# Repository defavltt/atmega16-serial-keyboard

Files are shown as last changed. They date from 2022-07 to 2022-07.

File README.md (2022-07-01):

# ATmega16 serial keyboard

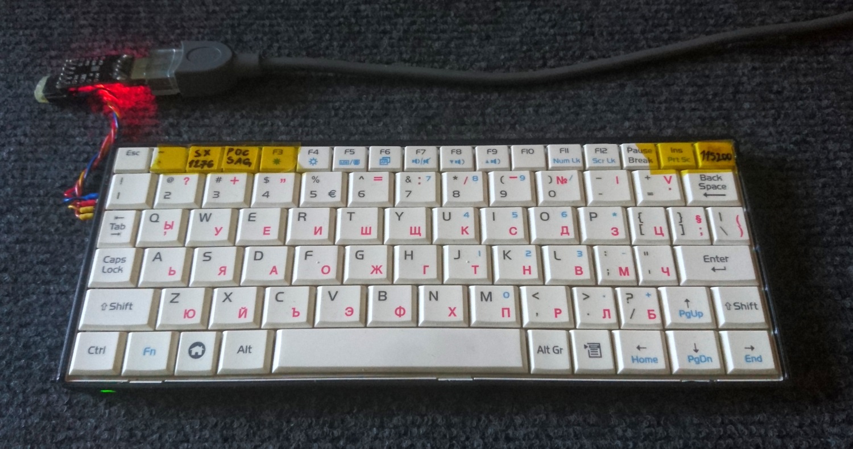
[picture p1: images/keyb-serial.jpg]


## Features

 - Key macros can be added in code
 
 - Caps toggle with LED indication
 
 - Select 115200 serial baud rate at power up (9600 default)
 
 - Send values outside ASCII range with non letter keys
 
 - Works with laptop mini keyboards 26-pin (28-pin with 2 being a short)

## Operation

When powering up, while the LED is lit, you can choose either: 9600 baud by not pressing DEL or 115200 by pressing DEL. After that you can choose a macro key mapping preset with F1 - F12. Finally when the LED is off you can start typing.

Toggling caps lock is done by a single press on the caps key. Shift key inverts it. When caps is on, the numbers change into symbols too.

_When designing an application at the other end of the serial cable, you may consider to take advantage of the non letter keys that send values (>200), as interface navigation. For example: ESC to exit out of options, HOME to exit out to start screen, ENTER to send a message or save an option, arrow keys for navigating through options and F1 - F12 for predefined functions._

# Hardware

Can be made with ATmega16/164/32/324/644/1284/8535 (44pin TQFP packege).

For 115200 serial baud rate a 16Mhz or a different suitable crystal is required, even though it's not included in the board design.
Board is designed for single side etching and some wire jumpers, vias are only for ground connection to the bottom layer. Feel free to improve it.

There are pads left on the PCB for ISP programming.

File for a 3D printed case is included. This case only suits keyboards with frame size - 211mm x 80mm.

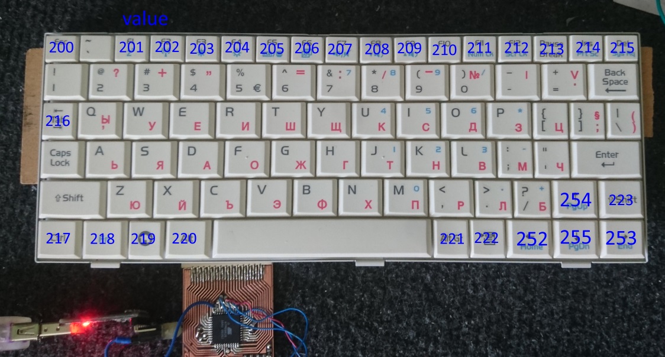
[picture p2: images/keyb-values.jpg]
  
_values that can be sent from the corresponding keys_

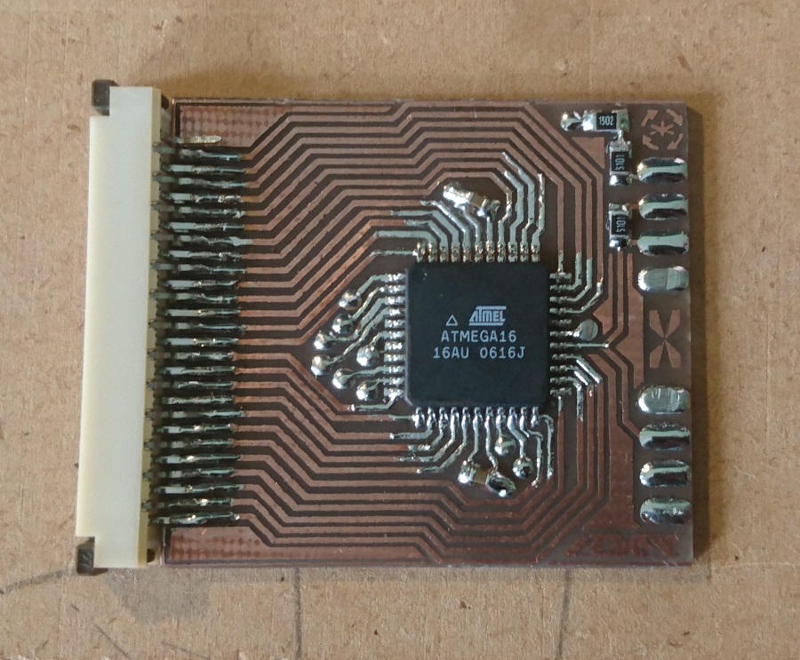
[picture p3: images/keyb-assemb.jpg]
  
_assembled board only with components, no jumper wires or crystal_

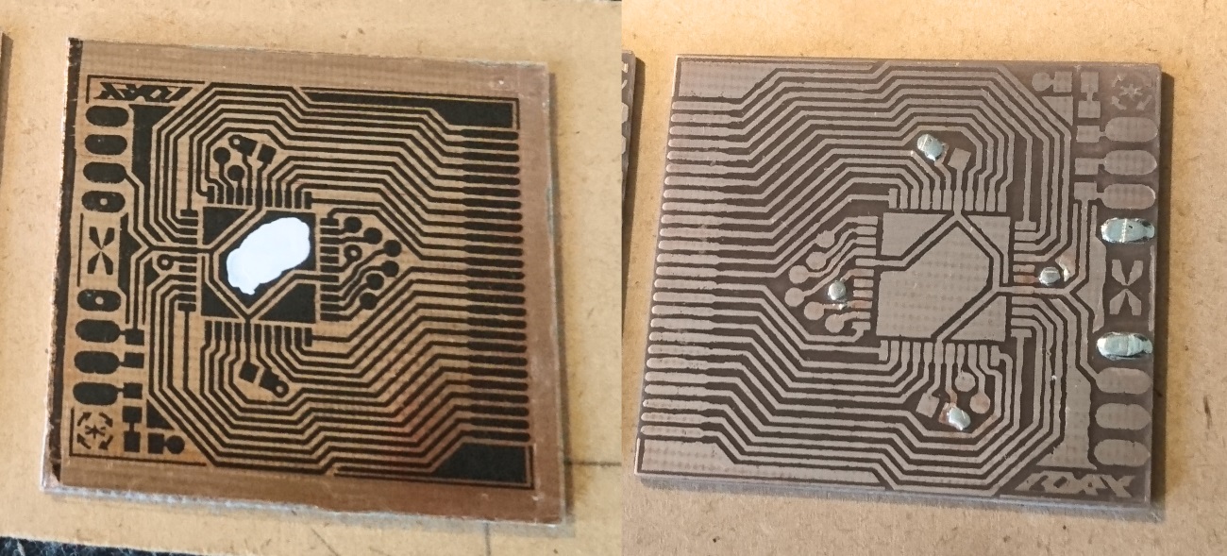
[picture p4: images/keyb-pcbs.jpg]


_< toner layer to protect copper from etchant | etched pcb >_

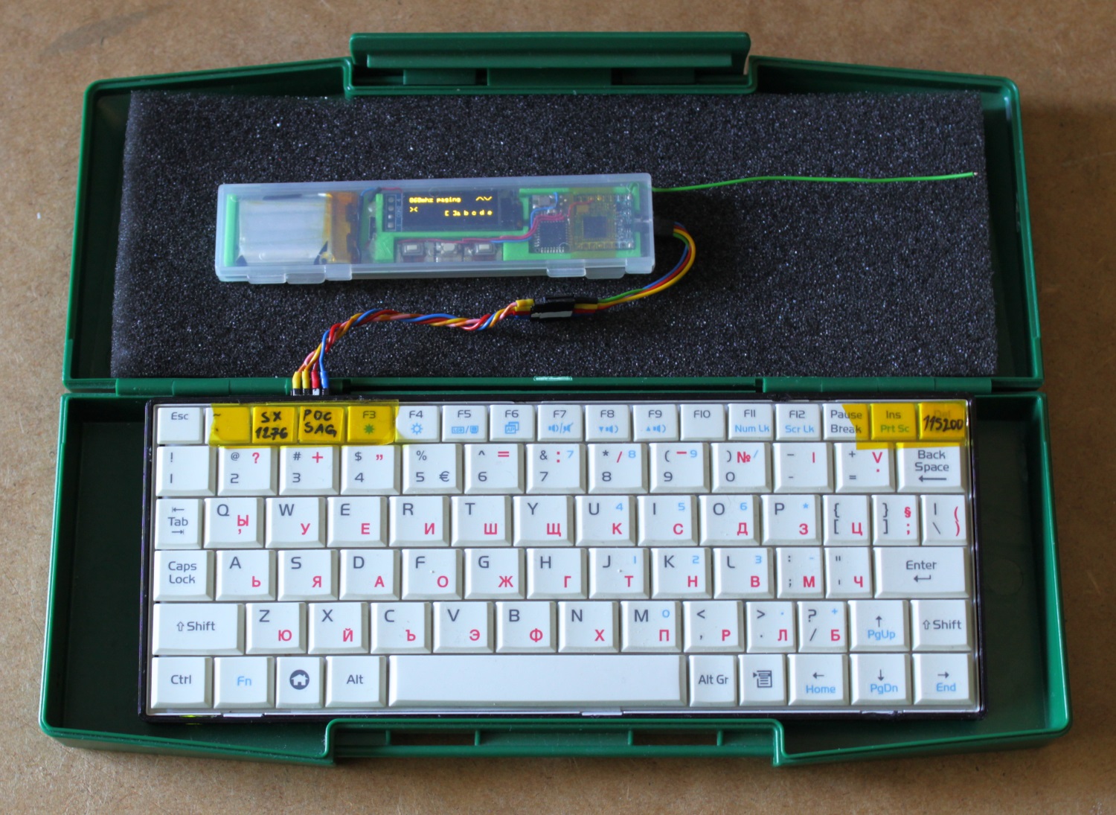
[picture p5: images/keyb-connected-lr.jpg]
  
_serial keyboard connected to a RFM95 LoRa communicator_

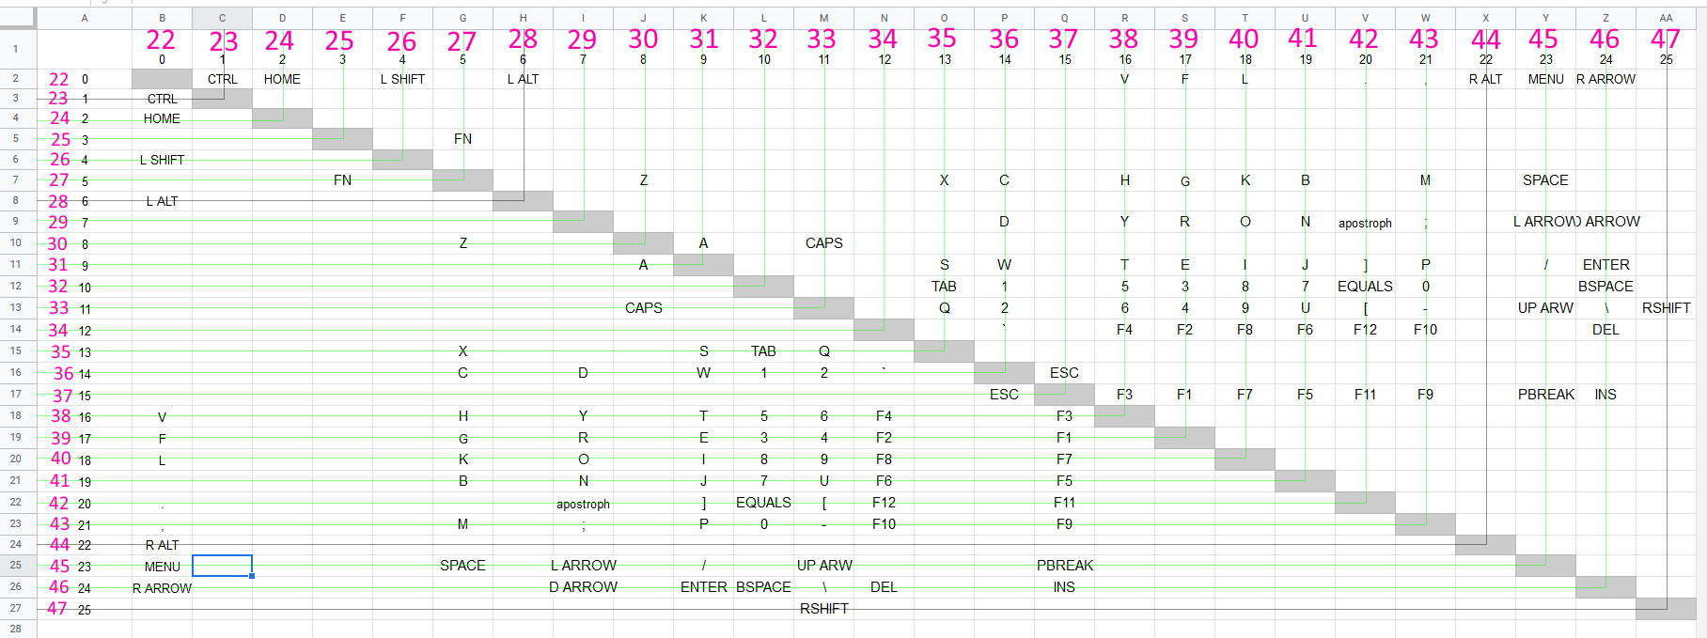
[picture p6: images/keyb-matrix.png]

_keyboard ribbon cable pin multiplexing mapping_

# Programming

 - Download and install [MightyCore](https://github.com/MCUdude/MightyCore)
 
 - Open code in IDE of choice
 
 - Configure board settings
 
   - Select your MCU and crystal frequency
   
   - Leave the rest of the board settings by default
   
   - If want, you can enable bootloader and leave out a reset pin on the serial connector for future configuring of the key macros.
   
 - Flash via ISP programmer and it's done.

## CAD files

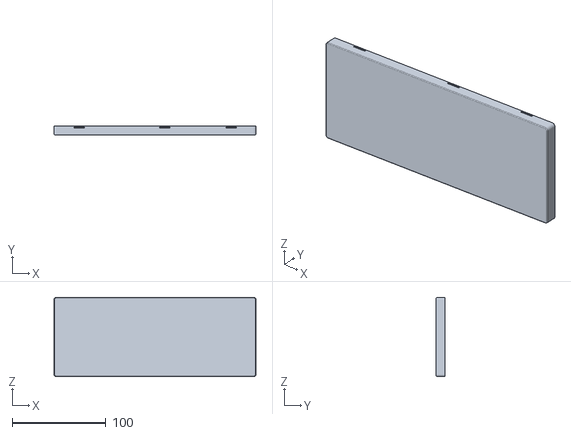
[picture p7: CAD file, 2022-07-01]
hardware/case/laptop keyboard case.stl
215.5 x 9.50 x 84.5

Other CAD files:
hardware/case/laptop keyboard case.f3d

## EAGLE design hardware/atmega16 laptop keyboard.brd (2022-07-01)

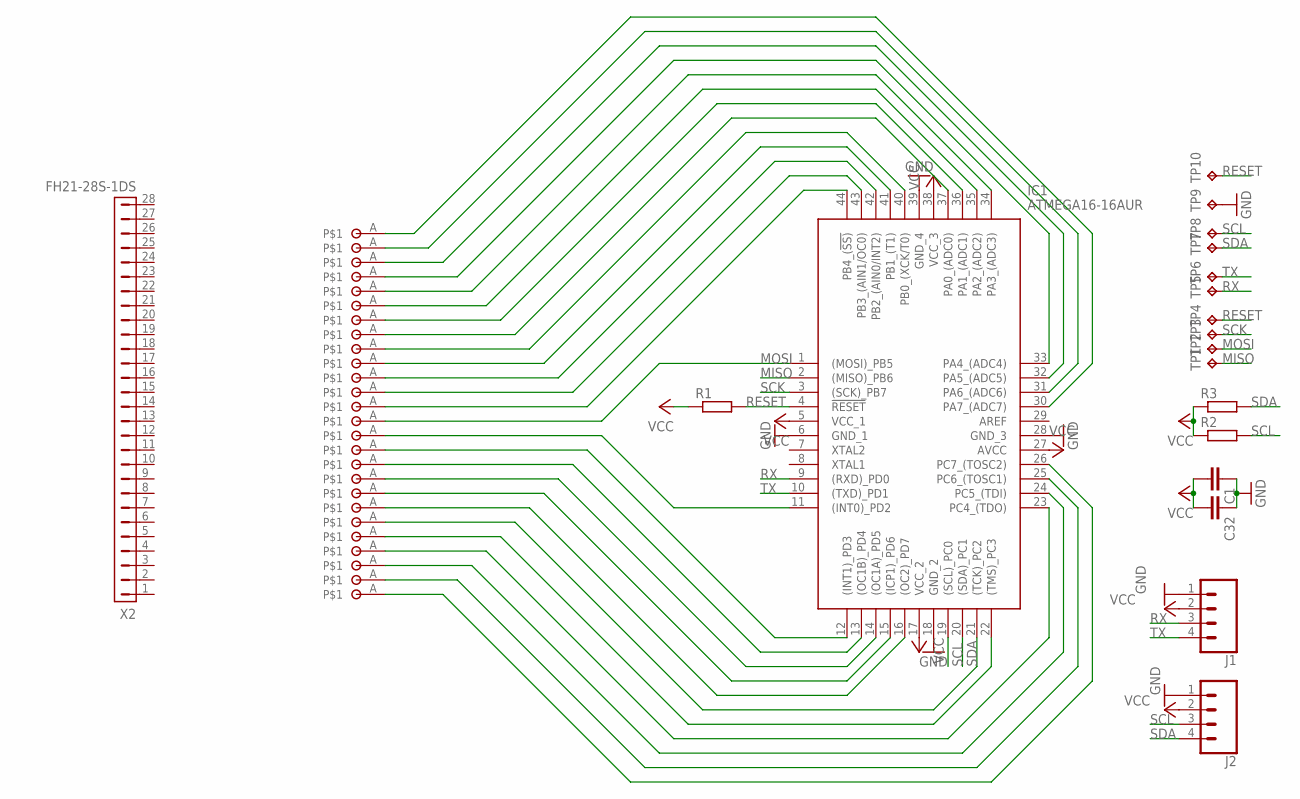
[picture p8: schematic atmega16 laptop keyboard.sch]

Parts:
C1, C32: C-EUC0805; C0805
IC1: ATMEGA16-16AUR; QFP80P1200X1200X120-44N
J1, J2: CONN_04LONGPADS; 1X04_LONGPADS
R1, R2, R3: R-EU_M0805; M0805
TP1, TP2, TP3, TP4, TP5, TP6, TP7, TP8, TP9, TP10: TPTP15R; TP15R
U$1, U$2, U$3, U$4, U$5, U$6, U$7, U$8, U$9, U$10, U$11, U$12, U$13, U$14, U$15, U$16, U$17, U$18, U$19, U$20, U$21, U$22, U$23, U$24, U$25, U$26: PAD1
X2: FH21-28S-1DS

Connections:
GND: C1.1, C32.1, IC1.6 (GND_1), IC1.18 (GND_2), IC1.28 (GND_3), IC1.39 (GND_4), J1.1, J2.1, TP9.TP
MISO: IC1.2 ((MISO)_PB6), TP1.TP
MOSI: IC1.1 ((MOSI)_PB5), TP2.TP, U$14.A
unnamed: IC1.11 ((INT0)_PD2), U$15.A
unnamed: IC1.12 ((INT1)_PD3), U$16.A
unnamed: IC1.13 ((OC1B)_PD4), U$17.A
unnamed: IC1.14 ((OC1A)_PD5), U$18.A
unnamed: IC1.15 ((ICP1)_PD6), U$19.A
unnamed: IC1.16 ((OC2)_PD7), U$20.A
unnamed: IC1.21 ((TCK)_PC2), U$21.A
unnamed: IC1.22 ((TMS)_PC3), U$22.A
unnamed: IC1.23 (PC4_(TDO)), U$23.A
unnamed: IC1.24 (PC5_(TDI)), U$24.A
unnamed: IC1.25 (PC6_(TOSC1)), U$25.A
unnamed: IC1.26 (PC7_(TOSC2)), U$26.A
unnamed: IC1.44 (PB4_(!SS)), U$13.A
unnamed: IC1.43 (PB3_(AIN1/OC0)), U$12.A
unnamed: IC1.42 (PB2_(AIN0/INT2)), U$11.A
unnamed: IC1.41 (PB1_(T1)), U$10.A
unnamed: IC1.40 (PB0_(XCK/T0)), U$9.A
unnamed: IC1.37 (PA0_(ADC0)), U$8.A
unnamed: IC1.36 (PA1_(ADC1)), U$7.A
unnamed: IC1.35 (PA2_(ADC2)), U$6.A
unnamed: IC1.34 (PA3_(ADC3)), U$5.A
unnamed: IC1.33 (PA4_(ADC4)), U$4.A
unnamed: IC1.32 (PA5_(ADC5)), U$3.A
unnamed: IC1.31 (PA6_(ADC6)), U$2.A
unnamed: IC1.30 (PA7_(ADC7)), U$1.A
RESET: IC1.4 (!RESET), R1.2, TP4.TP, TP10.TP
RX: IC1.9 ((RXD)_PD0), J1.3, TP5.TP
SCK: IC1.3 ((SCK)_PB7), TP3.TP
SCL: IC1.19 ((SCL)_PC0), J2.3, R2.2, TP8.TP
SDA: IC1.20 ((SDA)_PC1), J2.4, R3.2, TP7.TP
TX: IC1.10 ((TXD)_PD1), J1.4, TP6.TP
VCC: C1.2, C32.2, IC1.5 (VCC_1), IC1.17 (VCC_2), IC1.27 (AVCC), IC1.38 (VCC_3), J1.2, J2.2, R1.1, R2.1, R3.1

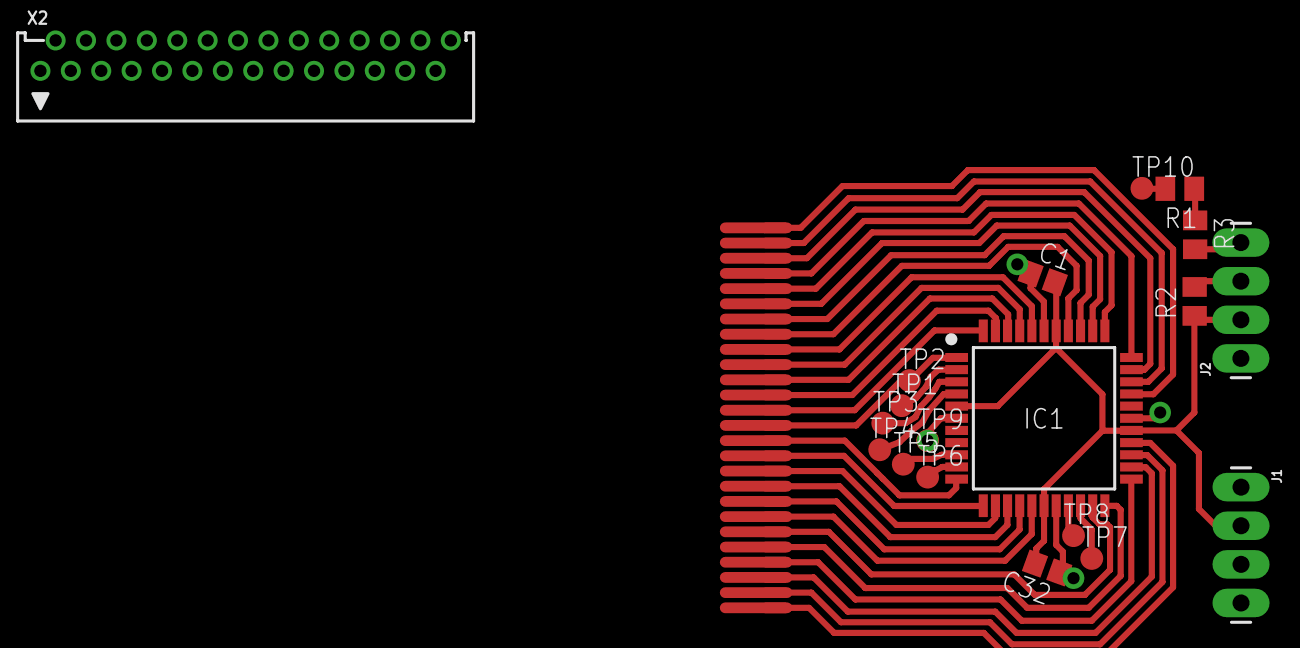
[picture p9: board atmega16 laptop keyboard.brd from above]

Board: 2 copper layers, 45 parts (0 on the bottom side), 35 nets.

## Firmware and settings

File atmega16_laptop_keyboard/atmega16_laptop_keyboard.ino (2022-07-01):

#define DR(port, pin) !((port >> pin) & B00000001) //fast pin reading

#define p22(state) if(DR(PINC, 6) == HIGH && DR(PINC, 6) != state) { statebuffer = 1; } else { statebuffer = 0; }  state = DR(PINC, 6);
#define p23(state) if(DR(PINC, 7) == HIGH && DR(PINC, 7) != state) { statebuffer = 1; } else { statebuffer = 0; }  state = DR(PINC, 7);
#define p24(state) if(DR(PINC, 4) == HIGH && DR(PINC, 4) != state) { statebuffer = 1; } else { statebuffer = 0; }  state = DR(PINC, 4);
#define p25(state) if(DR(PINC, 5) == HIGH && DR(PINC, 5) != state) { statebuffer = 1; } else { statebuffer = 0; }  state = DR(PINC, 5);
#define p26(state) if(DR(PINC, 2) == HIGH && DR(PINC, 2) != state) { statebuffer = 1; } else { statebuffer = 0; }  state = DR(PINC, 2);
#define p27(state) if(DR(PINC, 3) == HIGH && DR(PINC, 3) != state) { statebuffer = 1; } else { statebuffer = 0; }  state = DR(PINC, 3);
#define p28(state) if(DR(PIND, 6) == HIGH && DR(PIND, 6) != state) { statebuffer = 1; } else { statebuffer = 0; }  state = DR(PIND, 6);
#define p29(state) if(DR(PIND, 7) == HIGH && DR(PIND, 7) != state) { statebuffer = 1; } else { statebuffer = 0; }  state = DR(PIND, 7);
#define p30(state) if(DR(PIND, 4) == HIGH && DR(PIND, 4) != state) { statebuffer = 1; } else { statebuffer = 0; }  state = DR(PIND, 4);
#define p31(state) if(DR(PIND, 5) == HIGH && DR(PIND, 5) != state) { statebuffer = 1; } else { statebuffer = 0; }  state = DR(PIND, 5);
#define p32(state) if(DR(PIND, 2) == HIGH && DR(PIND, 2) != state) { statebuffer = 1; } else { statebuffer = 0; }  state = DR(PIND, 2);
#define p33(state) if(DR(PIND, 3) == HIGH && DR(PIND, 3) != state) { statebuffer = 1; } else { statebuffer = 0; }  state = DR(PIND, 3);
#define p34(state) if(DR(PINB, 4) == HIGH && DR(PINB, 4) != state) { statebuffer = 1; } else { statebuffer = 0; }  state = DR(PINB, 4);
#define p35(state) if(DR(PINB, 5) == HIGH && DR(PINB, 5) != state) { statebuffer = 1; } else { statebuffer = 0; }  state = DR(PINB, 5);
#define p36(state) if(DR(PINB, 2) == HIGH && DR(PINB, 2) != state) { statebuffer = 1; } else { statebuffer = 0; }  state = DR(PINB, 2);
#define p37(state) if(DR(PINB, 3) == HIGH && DR(PINB, 3) != state) { statebuffer = 1; } else { statebuffer = 0; }  state = DR(PINB, 3);
#define p38(state) if(DR(PINB, 0) == HIGH && DR(PINB, 0) != state) { statebuffer = 1; } else { statebuffer = 0; }  state = DR(PINB, 0);
#define p39(state) if(DR(PINB, 1) == HIGH && DR(PINB, 1) != state) { statebuffer = 1; } else { statebuffer = 0; }  state = DR(PINB, 1);
#define p40(state) if(DR(PINA, 1) == HIGH && DR(PINA, 1) != state) { statebuffer = 1; } else { statebuffer = 0; }  state = DR(PINA, 1);
#define p41(state) if(DR(PINA, 0) == HIGH && DR(PINA, 0) != state) { statebuffer = 1; } else { statebuffer = 0; }  state = DR(PINA, 0);
#define p42(state) if(DR(PINA, 3) == HIGH && DR(PINA, 3) != state) { statebuffer = 1; } else { statebuffer = 0; }  state = DR(PINA, 3);
#define p43(state) if(DR(PINA, 2) == HIGH && DR(PINA, 2) != state) { statebuffer = 1; } else { statebuffer = 0; }  state = DR(PINA, 2);
#define p44(state) if(DR(PINA, 5) == HIGH && DR(PINA, 5) != state) { statebuffer = 1; } else { statebuffer = 0; }  state = DR(PINA, 5);
#define p45(state) if(DR(PINA, 4) == HIGH && DR(PINA, 4) != state) { statebuffer = 1; } else { statebuffer = 0; }  state = DR(PINA, 4);
#define p46(state) if(DR(PINA, 7) == HIGH && DR(PINA, 7) != state) { statebuffer = 1; } else { statebuffer = 0; }  state = DR(PINA, 7);
#define p47(state) if(DR(PINA, 6) == HIGH && DR(PINA, 6) != state) { statebuffer = 1; } else { statebuffer = 0; }  state = DR(PINA, 6);

bool statebuffer;

bool keystate[81];

bool shiftkey;
bool capskey;

/*key macro presets*/
byte mode = 0; //0 - default map, 1 - sx1276 config, 2 - pocsag config

void setup() {
  Serial.begin(9600);
  pinMode(PIN_PC0, OUTPUT); //caps led
  
  while(true) {
    pulluppins();
    pinMode(PIN_PB4, OUTPUT);
    digitalWrite(PIN_PB4, LOW);
    p38(keystate[64]) if(statebuffer) { //38
      mode = 4; //F4
    }
    p39(keystate[65]) if(statebuffer) { //39
      mode = 2; //F2
    }
    p40(keystate[66]) if(statebuffer) { //40
      mode = 8; //F8
    }
    p41(keystate[67]) if(statebuffer) { //41
      mode = 6; //F6
    }
    p42(keystate[68]) if(statebuffer) { //42
      mode = 12; //F12
    }
    p43(keystate[69]) if(statebuffer) { //43
      mode = 10; //F10
    }
    p46(keystate[70]) if(statebuffer) { //46
      Serial.begin(115200); //DEL
    }
  
    pulluppins();
    pinMode(PIN_PB3, OUTPUT);
    digitalWrite(PIN_PB3, LOW);
    p38(keystate[72]) if(statebuffer) { //38
      mode = 3; //F3
    }
    p39(keystate[73]) if(statebuffer) { //39
      mode = 1; //F1
    }
    p40(keystate[74]) if(statebuffer) { //40
      mode = 7; //F7
    }
    p41(keystate[75]) if(statebuffer) { //41
      mode = 5; //F5
    }
    p42(keystate[76]) if(statebuffer) { //42
      mode = 11; //F11
    }
    p43(keystate[77]) if(statebuffer) { //43
      mode = 9; //F9
    }
    
    shiftkey = 1; //turn on led by enabling shift
    if(millis() > 3000) {
      return;
    }
  }
  shiftkey = 0; //turn off led by letting shift off


  
}

void loop() {
  scankeyboard();

}

void scankeyboard() {
  column0();
  column3();
  column5();
  column7();
  column8();
  column9();
  column10();
  column11();
  column12();
  column14();
  column15();
  
//  digitalWrite(PIN_PC0, shiftkey); //caps led
}

void pulluppins() {
  DDRC = 0b00000001; //make input
  if(shiftkey) {
    PORTC = 0b11111101; //1-6 //pull up
  } else {
    PORTC = 0b11111100; //1-6 //pull up
  }
  DDRD = 0b00000000;
  PORTD = 0b11111100; //7-12
  DDRB = 0b00000000;
  PORTB = 0b00111111; //13-18
  DDRA = 0b00000000;
  PORTA = 0b11111111; //19-26
}

void column0() { //22
  pulluppins();

  pinMode(PIN_PC6, OUTPUT);
  digitalWrite(PIN_PC6, LOW);
  
  p23(keystate[0]) if(statebuffer) { //23
    Serial.write(217); //CTRL
  }
  p24(keystate[1]) if(statebuffer) { //24
    Serial.write(219); //HOME
  }
//  p26(keystate[2]) if(statebuffer) { //26
//    Serial.print("L SHIFT");
//  }
  if(DR(PINC, 2)) {
    //text+=String("L SHIFT");
    if(capskey) {
      shiftkey = false;
    } else {
      shiftkey = true;
    }
  } else {
    shiftkey = capskey;
  }
  p28(keystate[3]) if(statebuffer) { //28
    Serial.write(220); //L ALT
  }
  if(shiftkey) {
    p38(keystate[4]) if(statebuffer) { //38
      Serial.print("V");
    }
    p39(keystate[5]) if(statebuffer) { //39
      Serial.print("F");
    }
    p40(keystate[6]) if(statebuffer) { //40
      Serial.print("L");
    }
    p42(keystate[7]) if(statebuffer) { //42
      Serial.print(">");
    }
    p43(keystate[8]) if(statebuffer) { //43
      Serial.print("<");
    }
  } else {
    p38(keystate[4]) if(statebuffer) { //38
      Serial.print("v");
    }
    p39(keystate[5]) if(statebuffer) { //39
      Serial.print("f");
    }
    p40(keystate[6]) if(statebuffer) { //40
      Serial.print("l");
    }
    p42(keystate[7]) if(statebuffer) { //42
      Serial.print(".");
    }
    p43(keystate[8]) if(statebuffer) { //43
      Serial.print(",");
    }
  }
  p44(keystate[9]) if(statebuffer) { //44
    Serial.write(221); //R ALT
  }
  p45(keystate[10]) if(statebuffer) { //45
    Serial.write(222); //MENU
  }
  p46(keystate[11]) if(statebuffer) { //46
    Serial.write(253); //RIGHT
  }
}

void column3() { //25
  pulluppins();

  pinMode(PIN_PC5, OUTPUT);
  digitalWrite(PIN_PC5, LOW);

  p27(keystate[12]) if(statebuffer) { //27
    Serial.write(218); //FN
  }
}

void column5() { //27
  pulluppins();

  pinMode(PIN_PC3, OUTPUT);
  digitalWrite(PIN_PC3, LOW);

  if(shiftkey) {
    p30(keystate[13]) if(statebuffer) { //30
      Serial.print("Z");
    }
    p35(keystate[14]) if(statebuffer) { //35
      Serial.print("X");
    }
    p36(keystate[15]) if(statebuffer) { //36
      Serial.print("C");
    }
    p38(keystate[16]) if(statebuffer) { //38
      Serial.print("H");
    }
    p39(keystate[17]) if(statebuffer) { //39
      Serial.print("G");
    }
    p40(keystate[18]) if(statebuffer) { //40
      Serial.print("K");
    }
    p41(keystate[19]) if(statebuffer) { //41
      Serial.print("B");
    }
    p43(keystate[20]) if(statebuffer) { //43
      Serial.print("M");
    }
  } else {
    p30(keystate[13]) if(statebuffer) { //30
      Serial.print("z");
    }
    p35(keystate[14]) if(statebuffer) { //35
      Serial.print("x");
    }
    p36(keystate[15]) if(statebuffer) { //36
      Serial.print("c");
    }
    p38(keystate[16]) if(statebuffer) { //38
      Serial.print("h");
    }
    p39(keystate[17]) if(statebuffer) { //39
      Serial.print("g");
    }
    p40(keystate[18]) if(statebuffer) { //40
      Serial.print("k");
    }
    p41(keystate[19]) if(statebuffer) { //41
      Serial.print("b");
    }
    p43(keystate[20]) if(statebuffer) { //43
      Serial.print("m");
    }
  }
  p45(keystate[21]) if(statebuffer) { //45
    Serial.print(" ");
  }
}

void column7() { //29
  pulluppins();

  pinMode(PIN_PD7, OUTPUT);
  digitalWrite(PIN_PD7, LOW);

  if(shiftkey) {
    p36(keystate[22]) if(statebuffer) { //36
      Serial.print("D");
    }
    p38(keystate[23]) if(statebuffer) { //38
      Serial.print("Y");
    }
    p39(keystate[24]) if(statebuffer) { //39
      Serial.print("R");
    }
    p40(keystate[25]) if(statebuffer) { //40
      Serial.print("O");
    }
    p41(keystate[26]) if(statebuffer) { //41
      Serial.print("N");
    }
    p42(keystate[27]) if(statebuffer) { //42
      Serial.print('"');
    }
    p43(keystate[28]) if(statebuffer) { //43
      Serial.print(":");
    }
  } else {
    p36(keystate[22]) if(statebuffer) { //36
      Serial.print("d");
    }
    p38(keystate[23]) if(statebuffer) { //38
      Serial.print("y");
    }
    p39(keystate[24]) if(statebuffer) { //39
      Serial.print("r");
    }
    p40(keystate[25]) if(statebuffer) { //40
      Serial.print("o");
    }
    p41(keystate[26]) if(statebuffer) { //41
      Serial.print("n");
    }
    p42(keystate[27]) if(statebuffer) { //42
      Serial.print("'");
    }
    p43(keystate[28]) if(statebuffer) { //43
      Serial.print(";");
    }
  }
  p45(keystate[29]) if(statebuffer) { //45
    Serial.write(252); //LEFT
  }
  p46(keystate[30]) if(statebuffer) { //46
    Serial.write(255); //DOWN
  }
}

void column8() { //30
  pulluppins();

  pinMode(PIN_PD4, OUTPUT);
  digitalWrite(PIN_PD4, LOW);

  if(shiftkey) {
    p31(keystate[31]) if(statebuffer) { //31
      Serial.print("A");
    }
  } else {
    p31(keystate[31]) if(statebuffer) { //31
      Serial.print("a");
    }
  }
  p33(keystate[32]) if(statebuffer) { //33
//    Serial.print("CAPS");
    capskey = !capskey;
  }
}

void column9() { //31
  pulluppins();

  pinMode(PIN_PD5, OUTPUT);
  digitalWrite(PIN_PD5, LOW);

  if(shiftkey) {
    p35(keystate[33]) if(statebuffer) { //35
      Serial.print("S");
    }
    p36(keystate[34]) if(statebuffer) { //36
      Serial.print("W");
    }
    p38(keystate[35]) if(statebuffer) { //38
      Serial.print("T");
    }
    p39(keystate[36]) if(statebuffer) { //39
      Serial.print("E");
    }
    p40(keystate[37]) if(statebuffer) { //40
      Serial.print("I");
    }
    p41(keystate[38]) if(statebuffer) { //41
      Serial.print("J");
    }
    p42(keystate[39]) if(statebuffer) { //42
      Serial.print("}");
    }
    p43(keystate[40]) if(statebuffer) { //43
      Serial.print("P");
    }
    p45(keystate[41]) if(statebuffer) { //45
      Serial.print("?");
    }
  } else {
    p35(keystate[33]) if(statebuffer) { //35
      Serial.print("s");
    }
    p36(keystate[34]) if(statebuffer) { //36
      Serial.print("w");
    }
    p38(keystate[35]) if(statebuffer) { //38
      Serial.print("t");
    }
    p39(keystate[36]) if(statebuffer) { //39
      Serial.print("e");
    }
    p40(keystate[37]) if(statebuffer) { //40
      Serial.print("i");
    }
    p41(keystate[38]) if(statebuffer) { //41
      Serial.print("j");
    }
    p42(keystate[39]) if(statebuffer) { //42
      Serial.print("]");
    }
    p43(keystate[40]) if(statebuffer) { //43
      Serial.print("p");
    }
    p45(keystate[41]) if(statebuffer) { //45
      Serial.print("/");
    }
  }
  p46(keystate[42]) if(statebuffer) { //46
    Serial.print("\n");
  }
}

void column10() { //32
  pulluppins();

  pinMode(PIN_PD2, OUTPUT);
  digitalWrite(PIN_PD2, LOW);

  p35(keystate[43]) if(statebuffer) { //35
    Serial.write(216); //TAB
  }
  if(shiftkey) {
    p36(keystate[44]) if(statebuffer) { //36
      Serial.print("!");
    }
    p38(keystate[45]) if(statebuffer) { //38
      Serial.print("%");
    }
    p39(keystate[46]) if(statebuffer) { //39
      Serial.print("#");
    }
    p40(keystate[47]) if(statebuffer) { //40
      Serial.print("*");
    }
    p41(keystate[48]) if(statebuffer) { //41
      Serial.print("&");
    }
    p42(keystate[49]) if(statebuffer) { //42
      Serial.print("+");
    }
    p43(keystate[50]) if(statebuffer) { //43
      Serial.print(")");
    }
  } else {
    p36(keystate[44]) if(statebuffer) { //36
      Serial.print("1");
    }
    p38(keystate[45]) if(statebuffer) { //38
      Serial.print("5");
    }
    p39(keystate[46]) if(statebuffer) { //39
      Serial.print("3");
    }
    p40(keystate[47]) if(statebuffer) { //40
      Serial.print("8");
    }
    p41(keystate[48]) if(statebuffer) { //41
      Serial.print("7");
    }
    p42(keystate[49]) if(statebuffer) { //42
      Serial.print("=");
    }
    p43(keystate[50]) if(statebuffer) { //43
      Serial.print("0");
    }
  }
  p46(keystate[51]) if(statebuffer) { //46
//    Serial.print("BSPACE");
    Serial.write(136);
  }
}

void column11() { //33
  pulluppins();

  pinMode(PIN_PD3, OUTPUT);
  digitalWrite(PIN_PD3, LOW);

  if(shiftkey) {
    p35(keystate[52]) if(statebuffer) { //35
      Serial.print("Q");
    }
    p36(keystate[53]) if(statebuffer) { //36
      Serial.print("@");
    }
    p38(keystate[54]) if(statebuffer) { //38
      Serial.print("^");
    }
    p39(keystate[55]) if(statebuffer) { //39
      Serial.print("$");
    }
    p40(keystate[56]) if(statebuffer) { //40
      Serial.print("(");
    }
    p41(keystate[57]) if(statebuffer) { //41
      Serial.print("U");
    }
    p42(keystate[58]) if(statebuffer) { //42
      Serial.print("{");
    }
    p43(keystate[59]) if(statebuffer) { //43
      Serial.print("_");
    }
    p46(keystate[61]) if(statebuffer) { //46
      Serial.print("|");
    }
  } else {
    p35(keystate[52]) if(statebuffer) { //35
      Serial.print("q");
    }
    p36(keystate[53]) if(statebuffer) { //36
      Serial.print("2");
    }
    p38(keystate[54]) if(statebuffer) { //38
      Serial.print("6");
    }
    p39(keystate[55]) if(statebuffer) { //39
      Serial.print("4");
    }
    p40(keystate[56]) if(statebuffer) { //40
      Serial.print("9");
    }
    p41(keystate[57]) if(statebuffer) { //41
      Serial.print("u");
    }
    p42(keystate[58]) if(statebuffer) { //42
      Serial.print("[");
    }
    p43(keystate[59]) if(statebuffer) { //43
      Serial.print("-");
    }
    p46(keystate[61]) if(statebuffer) { //46
      Serial.print("\\");
    }
  }
  p45(keystate[60]) if(statebuffer) { //45
    Serial.write(254); //UP
  }
  p47(keystate[62]) if(statebuffer) { //47
    Serial.write(223); //R SHIFT
  }
}

void column12() { //34
  pulluppins();

  pinMode(PIN_PB4, OUTPUT);
  digitalWrite(PIN_PB4, LOW);

  if(shiftkey) {
    p36(keystate[63]) if(statebuffer) { //36
      Serial.print("~");
    }
  } else {
    p36(keystate[63]) if(statebuffer) { //36
      Serial.print("`");
    }
  }
  p38(keystate[64]) if(statebuffer) { //38
    
    switch(mode) { //F4
      case 0:
        Serial.write(204);
        break;
      case 1:
        Serial.print("RTRANS");
        break;
      case 2:
        Serial.print("RTRANS");
        break;
    }
  }
  p39(keystate[65]) if(statebuffer) { //39
    switch(mode) { //F2
      case 0:
        Serial.write(202);
        break;
      case 1:
        Serial.print("PWR");
        break;
      case 2:
        Serial.print("FREQ");
        break;
    }
  }
  p40(keystate[66]) if(statebuffer) { //40
    switch(mode) { //F8
      case 0:
        Serial.write(208);
        break;
      case 1:
        Serial.print("PRMB");
        break;
      case 2:
        
        break;
    }
  }
  p41(keystate[67]) if(statebuffer) { //41
    switch(mode) { //F6
      case 0:
        Serial.write(206);
        break;
      case 1:
        Serial.print("SF");
        break;
      case 2:
        
        break;
    }
  }
  p42(keystate[68]) if(statebuffer) { //42
    switch(mode) { //F12
      case 0:
        Serial.write(212);
        break;
      case 1:
        
        break;
      case 2:
        
        break;
    }
  }
  p43(keystate[69]) if(statebuffer) { //43
    switch(mode) { //F10
      case 0:
        Serial.write(210);
        break;
      case 1:
        
        break;
      case 2:
        
        break;
    }
  }
  p46(keystate[70]) if(statebuffer) { //46
    Serial.write(215); //DEL
  }
}

void column14() { //36
  pulluppins();

  pinMode(PIN_PB2, OUTPUT);
  digitalWrite(PIN_PB2, LOW);

  p37(keystate[71]) if(statebuffer) { //37
    Serial.write(200); //ESC
  }
}

void column15() { //37
  pulluppins();

  pinMode(PIN_PB3, OUTPUT);
  digitalWrite(PIN_PB3, LOW);

  p38(keystate[72]) if(statebuffer) { //38
    switch(mode) { //F3
      case 0:
        Serial.write(203);
        break;
      case 1:
        Serial.print("RECV");
        break;
      case 2:
        Serial.print("BAUD");
        break;
    }
  }
  p39(keystate[73]) if(statebuffer) { //39
    switch(mode) { //F1
      case 0:
        Serial.write(201);
        break;
      case 1:
        Serial.print("FREQ");
        break;
      case 2:
        Serial.print("ADDR");
        break;
    }
  }
  p40(keystate[74]) if(statebuffer) { //40
    switch(mode) { //F7
      case 0:
        Serial.write(207);
        break;
      case 1:
        Serial.print("BW");
        break;
      case 2:
        
        break;
    }
  }
  p41(keystate[75]) if(statebuffer) { //41
    switch(mode) { //F5
      case 0:
        Serial.write(205);
        break;
      case 1:
        Serial.print("CTRANS");
        break;
      case 2:
        
        break;
    }
  }
  p42(keystate[76]) if(statebuffer) { //42
    switch(mode) { //F11
      case 0:
        Serial.write(211);
        break;
      case 1:
        
        break;
      case 2:
        
        break;
    }
  }
  p43(keystate[77]) if(statebuffer) { //43
    switch(mode) { //F9
      case 0:
        Serial.write(209);
        break;
      case 1:
        Serial.print("MODEM");
        break;
      case 2:
        
        break;
    }
  }
  p45(keystate[78]) if(statebuffer) { //45
    Serial.write(213); //PBREAK
  }
  p46(keystate[79]) if(statebuffer) { //46
    Serial.write(214); //INS
  }
}

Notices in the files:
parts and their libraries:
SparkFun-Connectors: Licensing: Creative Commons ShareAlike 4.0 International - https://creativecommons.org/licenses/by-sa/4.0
